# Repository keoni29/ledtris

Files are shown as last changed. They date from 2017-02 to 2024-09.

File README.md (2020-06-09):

# NES Ledtris
With the software and hardware described in this repository you can play classic NES Tetris on an LED display based on the popular WS2812b led strips.

>__Disclaimer__ Script for emulator only works under UNIX-like operating systems, because of the way serial ports are accessed. Feel free to modify this to work on windows.

# Contents
This repository contains everything you need to play Tetris for NES on a WS2812b
LED display. This includes:

- Arduino/AVR sourcecode for driving the LED display(s) and optional score display
- Startup script for FCEUX (NES emulator)
- Lua script for streaming gameplay data from FCEUX to LED matrix display.
- Instructions on how to build the LED display(s)
- DXF files for laser cutter

# Hardware
You will need the following items

__Playfield display__ measuring 20x10 pixels. Build instructions can be found in `cad/`

__LED display driver__ using an Arduino board or an AVR microcontroller.

- Arduino - See `arduino/README.md` - Tested on Arduino UNO rev3
- AVR - See `avr/README.md` - Tested on ATMega8A

__5 V power supply__ that can deliver at least 12 A. This is the minimum rated current required to drive all LEDs at full intensity.

> __DO NOT__ attempt to use USB power for this. This will damage the USB port or phone charger.

__Next Block display__ measuring 4x2 pixel. (optional)

__Score display__ used to show the player's score. Contains six 7-segment display digits.(optional)

> Both the Arduino and AVR firmware support the __Score display__, however I only made schematics for the AVR version. See `avr/schematic.png` You may need to connect to different pins for your Arduino board.

# Software
You need the FCEUX NES emulator, the `ledtris.lua` script and a Tetris (USA version) ROM.

## NES Emulator
Install FCEUX using your favorite package manager or download it here:
https://sourceforge.net/p/fceultra/code/HEAD/tree/

 Debian : 
 ```
 apt-get install fceux
 ```

 Archlinux : 
 ```
 pacman -S fceux
 ```

## Ledtris script
The emulator's functionality can be extended using lua scripts. The script `ledtris.lua` reads the framebuffer and the memory of the emulator and sends pixel and score data to the LED display driver via a serial port. 
> Script for emulator only works under UNIX-like operating systems, because of the way serial ports are accessed. 
## Tetris ROM
You will also need to acquire a copy of the USA version of Tetris for the NES.
Do a quick google search for "Tetris NES NTSC rom." 
Optionally rename the file to tetris.nes and place it in the same directory as `start_ledtris.sh`.

>I only tested this with the USA version. The PAL release might have some subtle differences.

# Putting everything together
Connect the display(s) to the LED driver.

Connect the LED driver (either Arduino or AVR) to the PC.

Apply 5V power to the LED driver. (NOT USB POWER)

Start FCEUX using the `start_ledtris.sh` script.
Usage:
```
./start_ledtris.sh [/path/to/tetris.nes]
```
You should now see some pixels light up on the display. 
> It looks a bit weird in the menus, because the lua script samples pixel colors 
> from the framebuffer rather than looking at the game's memory for Tetris bricks.
> Just press the `start` button a few times to get to the actual game.

# Troubleshooting
If you get a message complaining about `/dev/ttyACM0` not being accessible 
Find your serial port using `ls -l /dev/tty*` and enter the name of 
the serial port in ledtris.lua
```
	local portName = '/dev/ttyACM0'
```

Also make sure you have permission to use the serial port.

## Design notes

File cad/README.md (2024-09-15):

# LED Matrix Display using WS2812B
This is a guide for building an LED matrix display using the popular WS2812B LED strips.

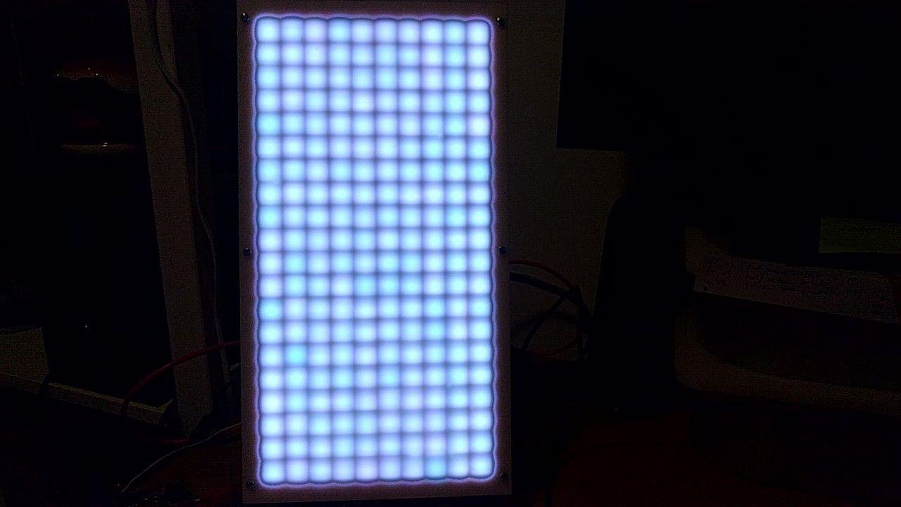
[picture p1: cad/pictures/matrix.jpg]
Matrix LED matrix display


# Parts
See the drawings for dimensions. The following parts are required:
- 200x WS2812B self-adhesive LED strip (300 LED / 5M)
- 24 AWG wire, for wiring up the LED strips
- M3 bolts and nuts (6x)
- 4mm birch plywood sheet
- 2mm white cast acrylic sheet
- 2mm painted aluminium sheet (i used radiator paint)

# Construction
The display consists of 3 sub assemblies: A painted aluminium plate with the LED strips, a light barrier and a light diffuser. Please refer to the drawings.

## Aluminium Plate + LED Strips
The LED strips are secured to an aluminium plate. It doubles as a heat spreader. Make sure to paint the surface before applying the LED strips, since there are copper contacts on the back. I lightly sanded the surface and applied a single coat of white radiator paint.

The LED strips are placed in a zig-zag pattern so the data-out can feed into the data-in pin of the next strip without running long wires across the display. I had to account for this in software.

## Light Barrier
This part makes the pixels look nice and square. The light barrier should be made out of an opaque material. I used 4mm birch plywood. The barrier consists of two halves. The pieces are almost identical, except the bottom piece has some room for cable management.
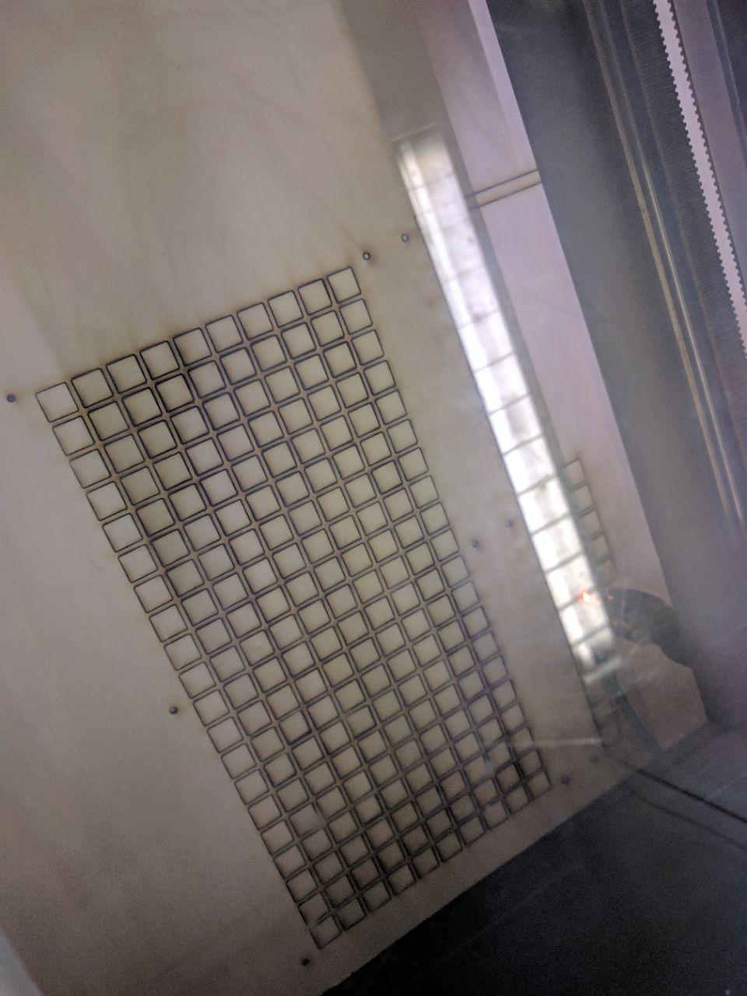
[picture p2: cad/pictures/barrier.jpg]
Barrier Light barrier


## Light Diffuser
The diffuser should be made using a semi-transparent plastic. I used 2mm white polycarbonate. Make sure your plastic can be used with a lasercutter.

# Wiring
Wire the LED strip power rails in parallel on the bottom of the display ( the bottom diffuser has a cutout to accommodate for this! ) The power rails of the LEDS are wired in parallel to reduce voltage drop across the strips. Wire the data out to the next strip's data in pin creating a zig-zag pattern starting from the bottom left. You can leave the data-out pin of the last strip unconnected. Attach a wire to the data-in pin of the first led-strip. This will later be used to drive the display. Attach a wire for 5 V and gnd for the power supply.

Be careful when soldering to the led strips on top of the painted aluminium. If the paint burns, the copper contact will short out trough the aluminium. I placed kapton tape below the strips at the ends to prevent this.

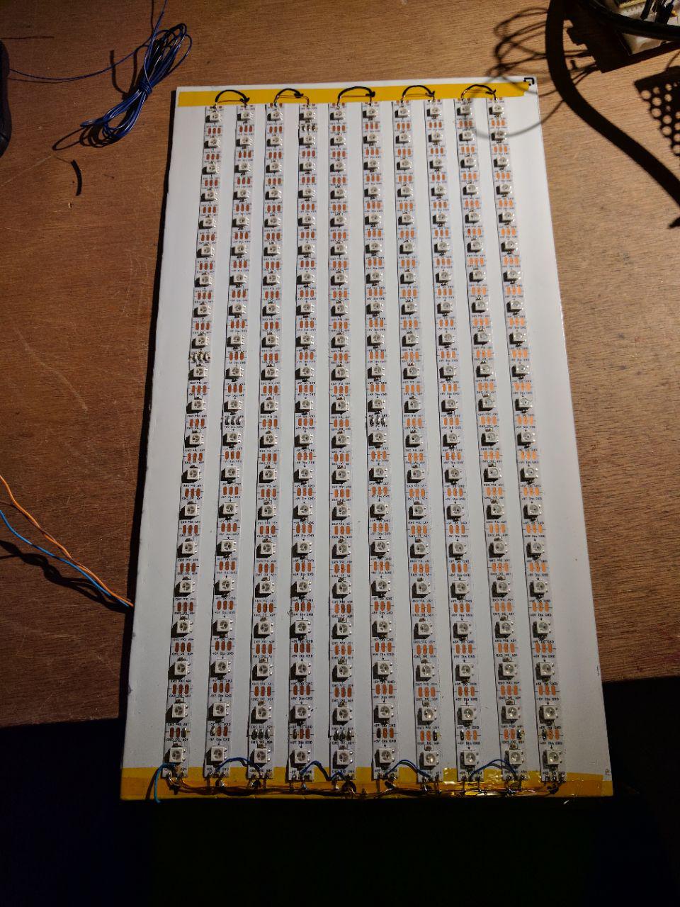
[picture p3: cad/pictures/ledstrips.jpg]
Wiring Ledstrip wiring


# Final Assembly
Stack the layers on top of eachother and secure them in place using M3 bolts.

# Software Used
I used LibreCAD to make the dxf drawings. It is available at http://librecad.org/cms/home.html “LibreCAD Website”

# Contact
If you have any questions regarding this guide please contact me:
Koen van Vliet <8by8mail@gmail.com>

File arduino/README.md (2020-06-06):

These are instructions for using the Arduino Uno as a LED display driver for Ledtris.

# Connections
- Connect `5V` of the display to a 5VDC, 12A power supply. This is the minimum current rating if you want to drive all LEDs at their highest intensity.
- Connect `GND` of the display to the Arduino's and the power supply's `GND`
- Connect `Din` of the display to the Arduino's `A0` pin

Optionally you can connect a MAX7219-based seven segment display for showing the score.
You need at least 6 digits to display the score.

max7219 display module

- Connect `VCC` of the MAX7219 to the Arduino's `5V` pin
- Connect `GND` of the MAX7219 to the Arduino's `GND` pin
- Connect `CLK` of the MAX7219 to the Arduino's `SPI Clock` pin (pin 13 for Arduino UNO)
- Connect `DIN` of the MAX7219 to the Arduino's `SPI MOSI` pin (pin 11 for Arduino UNO)
- Connect `CS` of the MAX7219 to the Arduino's `CS` pin. Default is pin 9, but this can be changed in the code.

# Building and uploading
1. Open `ledtris.ino` in the Arduino IDE.
2. Upload the sketch to your Arduino Uno or compatible.

To verify you did everything right

3. Start the emulator using the startup script `start_ledtris.sh`

You should now see some pixels lighting up on the display.

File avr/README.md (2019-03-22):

These are instructions for making a LED display driver for Ledtris using the ATMega8A microcontroller.

# Schematics
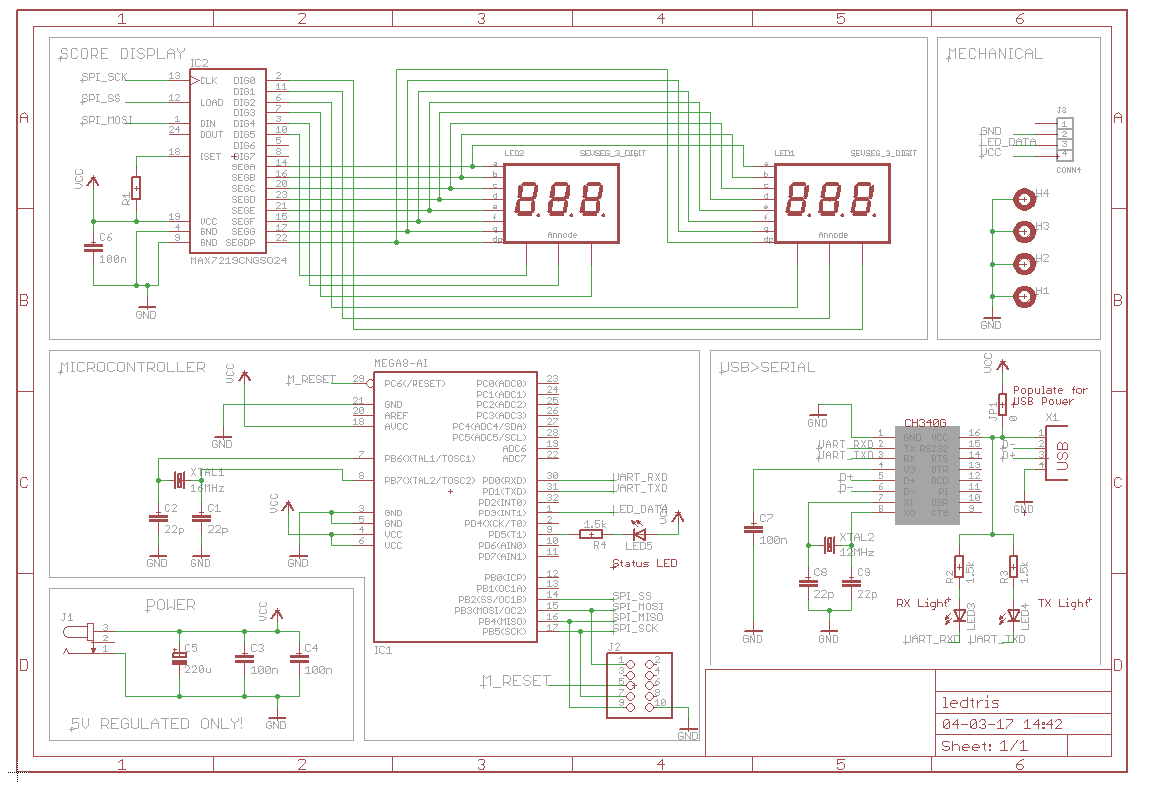
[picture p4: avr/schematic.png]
Schematic Ledtris LED driver schematic using ATMega8A microcontroller.


# Building and uploading
Install the following packages using your favorite package manager.

- `avr-gcc` - AVR GNU C compiler
- `avr-libc` - AVR Standard C Library
- `avrdude` - Driver program for "simple" Atmel AVR MCU programmer

The makefile has targets for programming the
fuse bits and the flash memory. The fuse bits have to be programmed once to set up the oscillator.
 1. To build simply run `make`
 2. Program the fuse bits using `make fuses`
 3. Then program the flash using `make flash`

>This AVR firmware has been tested with an ATMega8A microcontroller.
>If you wish to use a different microcontroller, please change the following lines of the 
>Makefile.
>```
>    DEVICE = atmega8
>    AVRDUDE_DEV = m8
>```
>Both DEVICE and AVRDUDE_DEV need to be changed if you are using a different microcontroller.
>
>- DEVICE is passed to `avr-gcc` using the `-mmcu` option.
>- AVRDUDE_DEV is passed to `avrdude` using the `-p` option.
>
>If you wish to use a programmer other than usbasp, please change the following line in of the Makefile.
>```
>    AVRDUDE_TOOL = usbasp
>```

# Troubleshooting
If you get the following error while programming the fuses or flash memory
```
avrdude: Warning: cannot open USB device: Permission denied
```
try creating a new udev rule for /etc/udev/rules.d/99-USBasp.rules
```
SUBSYSTEM=="usb", ATTR{product}=="USBasp", ATTR{idProduct}=="05dc", ATTRS{idVendor}=="16c0", MODE="0666"
```

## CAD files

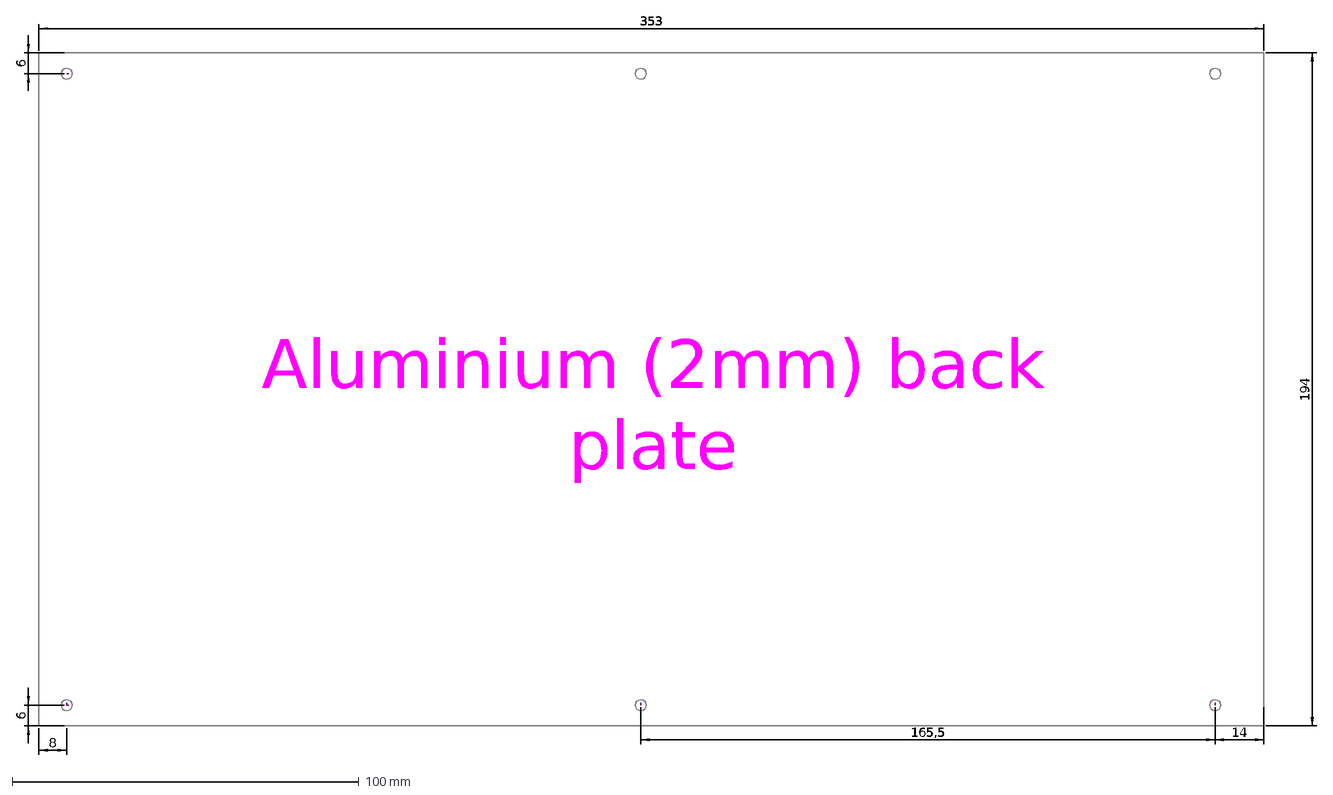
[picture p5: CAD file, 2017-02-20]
cad/04 - Aluminium Plate.dxf
Aluminium (2mm) back plate
353
194
14
165,5
6
8

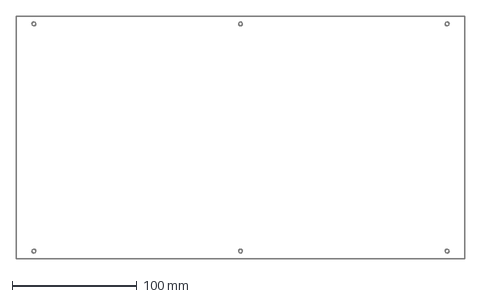
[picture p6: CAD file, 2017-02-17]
cad/01 - Light Diffuser.dxf
359.0 x 194.0 mm

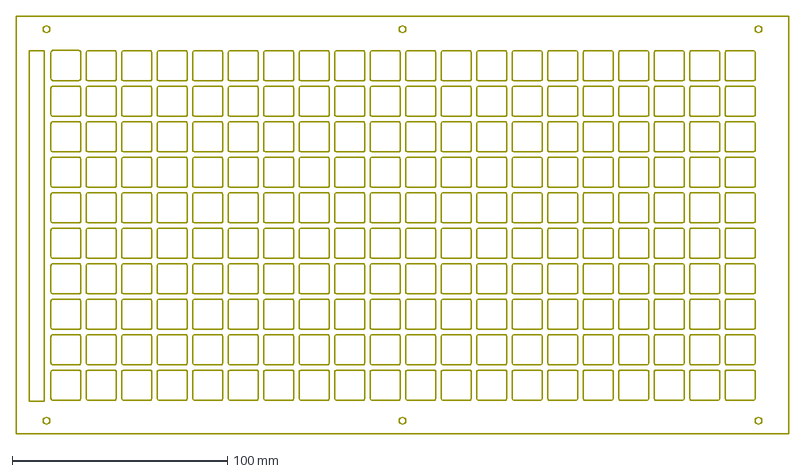
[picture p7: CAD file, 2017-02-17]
cad/03 - Barrier (bottom).dxf
359.0 x 194.0 mm

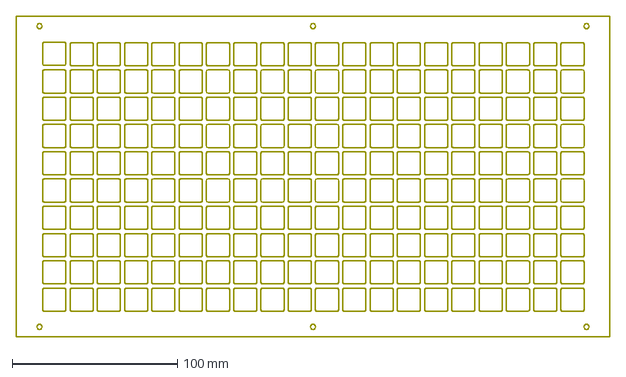
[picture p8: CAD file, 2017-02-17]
cad/02 - Barrier (top).dxf
359.0 x 194.0 mm

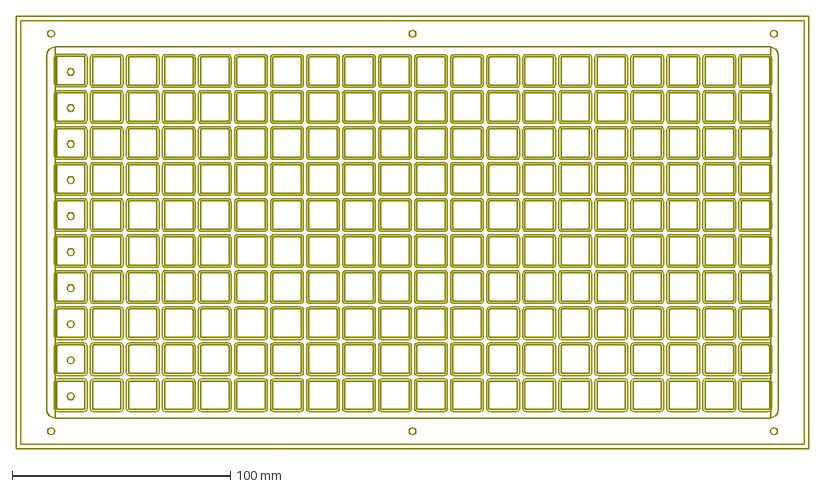
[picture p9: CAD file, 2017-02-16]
cad/matrix-exploded.dxf
363.0 x 198.0 mm

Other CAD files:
cad/Total Assembly.dxf

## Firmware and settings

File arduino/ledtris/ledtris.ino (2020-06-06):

/* Filename: ledtris.ino
 * Project: NES ledtris
 * Author: Koen van Vliet
 *
 * This sketch uses the Adafruit Neopixel library
 * which can be found here:
 *   https://github.com/adafruit/Adafruit_NeoPixel
 *
 * Max frame rate is 30 Hz (limitation of the WS2812B)
 * 
 */
#include <Adafruit_NeoPixel.h>
#include <SPI.h>
#ifdef __AVR__
  #include <avr/power.h>
#endif

/* User defined data pin for driving the WS2812B */
#define PIN            A0

/* User defined LOAD/CS pin for driving the MAX7219 */
#define SS_PIN          9

/* The number of LEDs in the display(s) combined */
#define NOF_PIXELS      208

/* Seven segment display driver MAX7219 register addresses */
#define DIG 0x1
#define DECODE 0x9
#define INTENSITY 0xA
#define SCAN_LIMIT 0x0B
#define SHDN 0xC
#define DISPLAY_TEST 0x0F

/* Create a new neopixel object specifying the
 * amount of pixels, data pin, data format and frequency */
Adafruit_NeoPixel pixels = Adafruit_NeoPixel(NOF_PIXELS, PIN, NEO_GRB + NEO_KHZ800);

void max7219_write(int address, int data)
{
  digitalWrite(SS_PIN, LOW);
  SPI.transfer(address);
  SPI.transfer(data);
  digitalWrite(SS_PIN, HIGH);
}

void max7219_init()
{
  int i;
  max7219_write(DECODE, 0xFF);  /* Decode all digits */
  max7219_write(SCAN_LIMIT, 5);  /* Limit scan digits 0..5 */
  max7219_write(INTENSITY, 0x7); /* Half intensity */
  max7219_write(SHDN, 0x1);  /* Turn ON display */
  max7219_write(DISPLAY_TEST, 0x0); /* Disable display test mode! */

  /* Turn all segments off */
  for(i = 0; i < 6; i++)
  {
    max7219_write(DIG + i, 0xF);
  }
}

void max7219_display(uint32_t number)
{
  for(int i = 0; i < 6; i++)
  {
      max7219_write(DIG + i, number % 10);
      number /= 10;
  }
}

void setup()
{
  /* Initialize the library and clear the display. */
  pixels.begin();

  for (int i = 0; i < NOF_PIXELS; ++i)
  {
    pixels.setPixelColor(i, 0);
  }

  pixels.show();

  /* Set up SPI and initialize sevseg display driver  */
  SPI.begin();
  SPI.setDataMode(SPI_MODE0);
  SPI.setClockDivider(SPI_CLOCK_DIV16);  // TODO make this a higher clock rate
  SPI.setBitOrder(MSBFIRST);
  digitalWrite(SS_PIN, HIGH);
  pinMode(SS_PIN, OUTPUT);
  max7219_init();

  /* Begin serial with maximum baudrate for uno. */
  Serial.begin(1000000);

  /* Flush serial receive buffer */
  while(Serial.available())
  {
    Serial.read();
  }
}

void loop()
{
  uint8_t r, g, b, s1, s2, s3;
  uint32_t score;
  static uint32_t prevscore = -1;

  /* Frame synchronization */
  do
  {
    while(!Serial.available());
    r = Serial.read();
  } while (r != 0xFF);

  /* Receive a frame. */
  for(int i = 0; i < NOF_PIXELS; ++i)
  {
    while(!Serial.available());
    r = Serial.read();

    while(!Serial.available());
    g = Serial.read();

    while(!Serial.available());
    b = Serial.read();

    pixels.setPixelColor(i, pixels.Color(r, g, b));
  }

  /* Receive current score and write to sevseg display if it has changed since the last frame. */
  while(!Serial.available());
  s1 = Serial.read();
  while(!Serial.available());
  s2 = Serial.read();
  while(!Serial.available());
  s3 = Serial.read();

  score = ((uint32_t)s1 << 16)  + ((uint16_t)s2 << 8) + s3;

  if (score != prevscore)
  {
    max7219_display(score);
  }
  prevscore = score;

  /* Push pixels to the display */
  pixels.show();
}

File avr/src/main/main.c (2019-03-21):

/**
 * Filename: main.c
 * Project: NES Ledtris
 * Author: Koen van Vliet <8by8mail@gmail.com>
 * 
 * AVR version of ledtris display driver
 *
 * Uses the light_ws2812 library, which can be found here:
 *   https://github.com/cpldcpu/light_ws2812
 * 
 * Usage:
 *      Send serial data to uart RXD pin (In case of the ATMega8A this is PD0)
 *      1. Send FRAME_SYNC (default 0xFF) to synchronize the display
 *          It is advised to reserve the FRAME_SYNC character for synchronization
 *      
 *      2. Send the pixel RGB data. Each pixel is 3 bytes in order 
 *          red, green, blue. In total 3 x NOF_PIXELS bytes are sent.
 *      
 *      3. Only if score display is enabled using ENABLE_SCORE_DISPLAY
 *          Send 3 bytes for the score display MSB first.
 *      
 */

#include "system_config.h"
////#include <util/delay.h>
#include "light_ws2812.h"
#include "score_display.h"
#include "uart.h"
#include "alive_led.h"

/**
 * The number of LEDs in the display(s) combined.
 */
#define NOF_PIXELS 208

/**
 * Enables the seven segment score display.
 */
#define ENABLE_SCORE_DISPLAY

/** Synchronization character indicating the start of a frame. */
#define FRAME_SYNC 0xFF

/** Framebuffer */
struct cRGB led[NOF_PIXELS];


void update_score_display(void);


int main(void)
{
	const char hello[] = "LEDTRIS - kv 2017\n";
    uint8_t i;

	uart_init();
    alive_led_init();
    ////_delay_ms(100);
	score_display_init();
	score_display_set(0);

	uart_write_string(hello);

	while(1)
	{
		/* Wait for frame synchronization character. */
        while(uart_read() != FRAME_SYNC)
        {
            ;
        }

		/* Receive pixel RGB data and store frame in framebuffer. */
		for (i = 0; i < NOF_PIXELS; ++i)
		{
			led[i].r = uart_read();
			led[i].g = uart_read();
			led[i].b = uart_read();
		}

        update_score_display();

		/* Push frame to display(s). */
		ws2812_setleds(led, NOF_PIXELS);

        /** 
         * Toggle 'alive' LED to indicate the frame was 
         * received and processed. 
         */
		alive_led_toggle();
	}
}


/** Read score from UART and update the score display if score has changed. */
inline void update_score_display(void)
{
#ifdef ENABLE_SCORE_DISPLAY
    uint8_t s1, s2, s3;
    uint32_t score;
    static uint32_t score_prev = 0;

    /* Read score bytes */ 
    s1 = uart_read();
    s2 = uart_read();
    s3 = uart_read();

    /* Pack score bytes into a single 32 bit value */
    score = ((uint32_t)s1 << 16) + ((uint32_t)s2 << 8)  + s3;

    /* Only update score display when score changes. */
    if (score != score_prev)
    {	
        score_display_set(score);
    }
    score_prev = score;
#endif // ENABLE_SCORE_DISPLAY
}

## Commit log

2017-01-09 Sending pixel data to LED display
2017-01-11 Added arduino sketch, updated readme and changed a lot of vars to locals.
2017-01-31 Fixed partial frames being sent
    [ledtris.ino]
2017-01-31 Increase framerate and reduce brightness
2017-01-31 Sync frames
2017-02-16 Added detailed drawings for laser cutter
    [ledtris.skp, matrix.dxf]
2017-02-16 Moving holes
    [matrix.dxf]
2017-02-16 Cleaning up dxf for laser cutter
    [matrix-exploded.dxf, matrix.dxf]
2017-02-17 Ready for laser
    [barrier-bottom.dxf, barrier-top.dxf, diffuser.dxf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]
2017-02-20 Short guide and renamed files
    [01 - Light Diffuser.dxf, 02 - Barrier (top).dxf, 03 - Barrier (bottom).dxf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]
2017-02-27 Led matrix working on avr
2017-02-27 Score display and lowered framerate for AVR.
2017-04-06 Changed led data pin and score only gets updated when changed
2017-04-12 Changed fuses for MCU
2017-04-12 Doubled baudrate, increased framerate from 25fps to 30 and fixed bug in score
2017-04-13 Ported changes in avr code to arduino
2019-03-17 Changed project structure and added schematic
